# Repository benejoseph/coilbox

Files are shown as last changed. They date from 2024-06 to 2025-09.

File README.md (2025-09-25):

**The goal of this is to make a box that you can put something in and make that thing experience a magnetic field.**

**The Arduino board is there to drive a signal of your choosing. In this example it's just making a sinusoid.**

1. rp2040 propmaker from adafruit goes in the bottom
2. 24 AWG magnet wire is wrapped around the top pocket
3. put the device under test in the box
4. blue light goes on when coil is on

Other pro tips
1. The spindle is there so you can wrap your magnet wire aroudn that spindle, and then thread through the box.  Probably the spindle the magnet wire came on is too small.  Or, in "params" in the CAD program you can just change "flange top height" and "flange bottom height" to be larger and print it larger so that your magnet wire spindle can fit.
2. jig2 is the name of the FreeCAD file that has the coil box 
3. I did probably 100 wraps of 24 AWG and got about 5 ohms, and easily got over +/-400 uT of field in the box.  This was most of the 4 oz roll of 24 AWG magnet wire. 
4. I ended up drilling and tapping M2.5 threads into the holes in the back.  I recommend getting a kit of this stuff.  In the end I used 4x M2.5 * 12mm screws, M2.5 * 10mm female-female spacers, and M2.5 * 6mm screws to attach the propmaker.  And... the two holes near the terminal of the propmaker is too narrow to get the screws in. oops.
5. IDE setup -- follow the [adafruit instructions](https://learn.adafruit.com/adafruit-rp2040-prop-maker-feather/arduino-ide-setup) for the rp2040 prop maker.

### pictures of the box completed
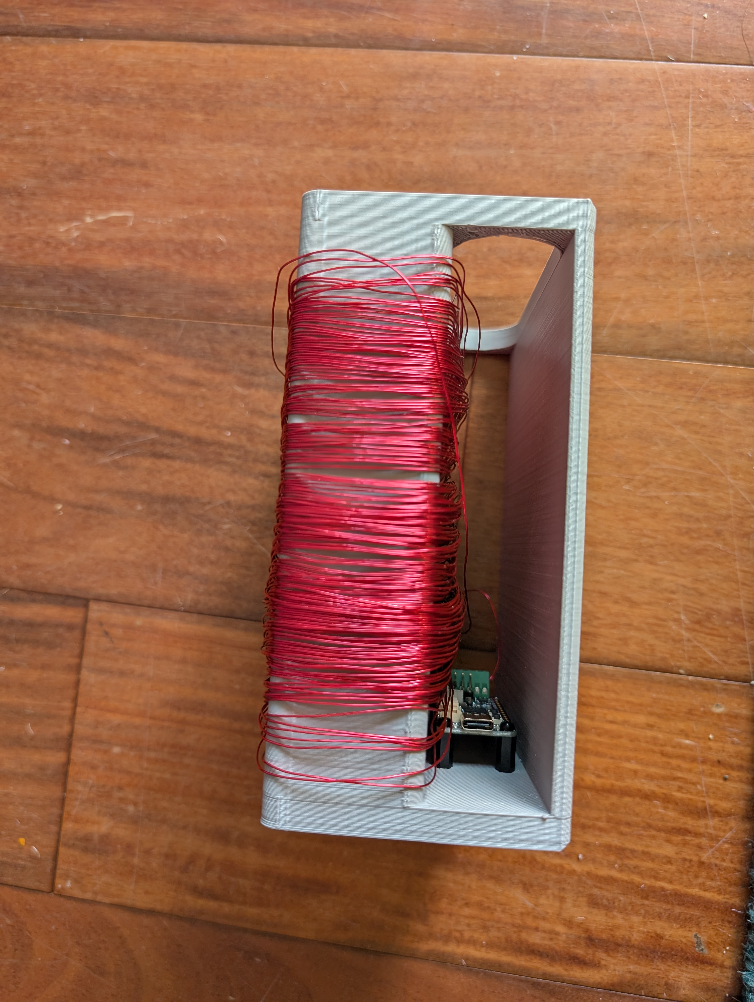
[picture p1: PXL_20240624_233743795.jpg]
looking into the box Looking into the box

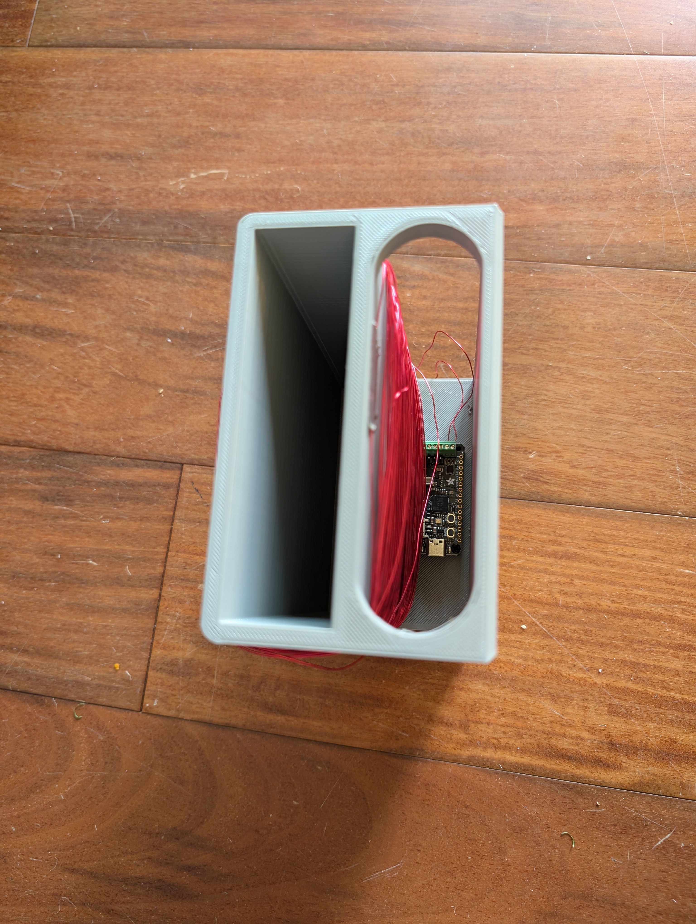
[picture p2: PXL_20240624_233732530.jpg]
side view Side View

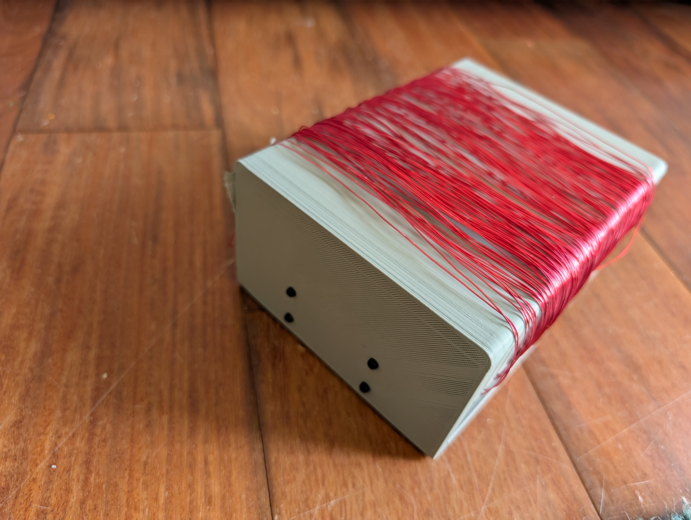
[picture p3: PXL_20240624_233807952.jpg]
rear view Rear View


### 15hz sinuosid (measured output, measured output PSD)
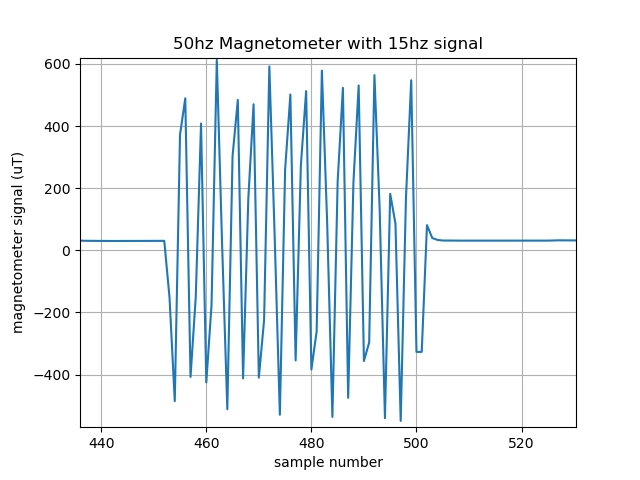
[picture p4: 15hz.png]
15hz time series from make_sinusoid

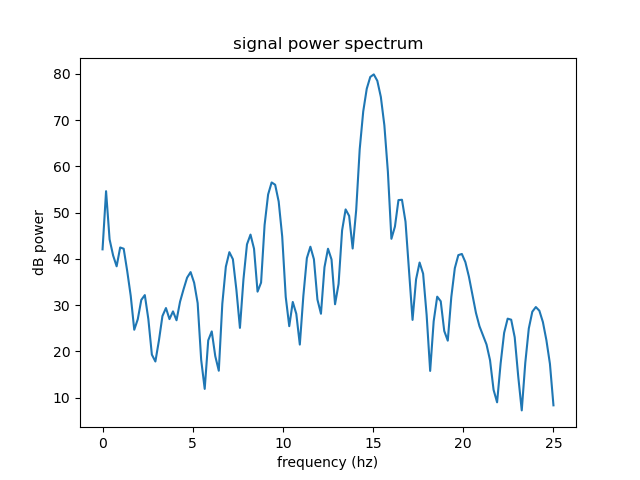
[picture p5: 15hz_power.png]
15hz PSD


### pulse (input waveform, measured output)
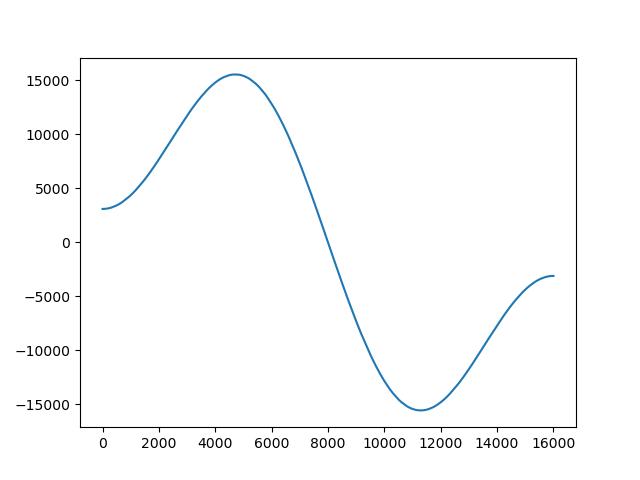
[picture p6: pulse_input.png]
pulse input waveform

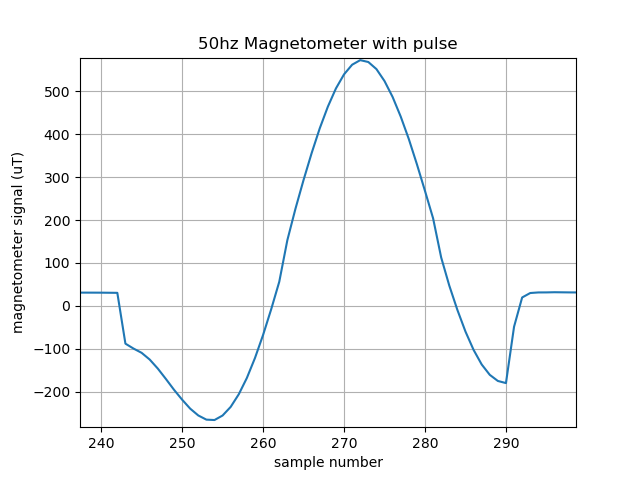
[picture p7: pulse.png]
pulse output


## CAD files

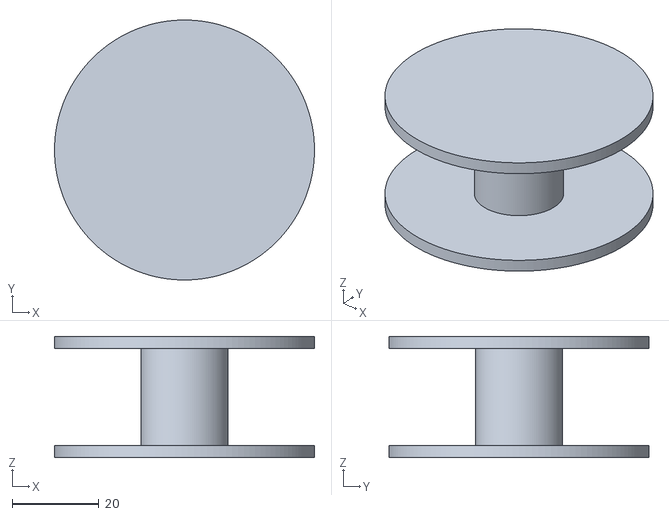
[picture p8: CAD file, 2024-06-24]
spindle-Body.stl
60.0 x 60.0 x 28.0

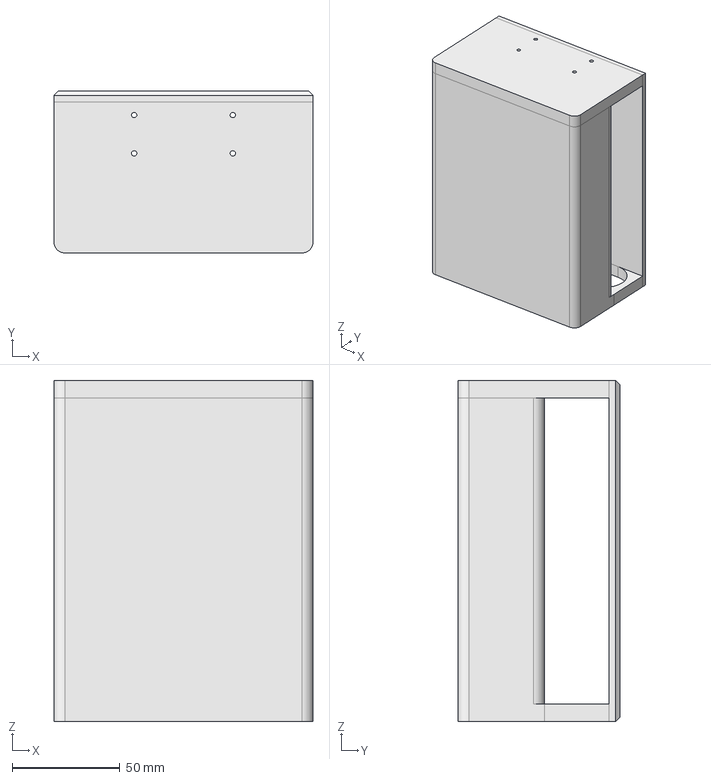
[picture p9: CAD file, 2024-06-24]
jig2.FCStd
120.0 x 75.0 x 158.0 mm

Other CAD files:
spindle.FCStd
jig2-Body.stl

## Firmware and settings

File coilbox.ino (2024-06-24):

#include <Adafruit_NeoPixel.h>
#include <Adafruit_LIS3DH.h>
#include <Adafruit_Sensor.h>
#include <I2S.h>

#include "sinusoid_samples.h"

#define ON_BOARD_RGB_PIN (D4)
#define BEACON_PERIOD_MILLIS (5000)
#define VOLUME_DOWN_BITS (2)

int led = LED_BUILTIN;
Adafruit_NeoPixel on_board_rgb_led = Adafruit_NeoPixel(1, ON_BOARD_RGB_PIN, NEO_GRB + NEO_KHZ800);
Adafruit_LIS3DH accel = Adafruit_LIS3DH();
unsigned int count = 0;

I2S i2s(OUTPUT);

bool is_playing_sound = false;

void PlayI2S(const int16_t *data, uint32_t len, uint32_t rate) {
  is_playing_sound = true;

  // start I2S at the sample rate with 16-bits per sample
  if (!i2s.begin(rate)) {
    Serial.println("Failed to initialize I2S!");
    delay(500);
    i2s.end();
    return;
  }
  
  for(uint32_t i=0; i<len; i++) {
   // uint16_t sample = (uint16_t)data[i] * 32;
    // write the same sample twice, once for left and once for the right channel
    int32_t signed_sample = static_cast<int32_t>(data[i]);
    signed_sample >>= VOLUME_DOWN_BITS;
    i2s.write(signed_sample);
    i2s.write(signed_sample);
  }
  i2s.end();
  is_playing_sound = false;
}


void setup() {
  pinMode(PIN_EXTERNAL_POWER, OUTPUT);

  // Some boards work best if we also make a serial connection
  Serial.begin(115200);

  // set LED to be an output pin
  pinMode(led, OUTPUT);
  on_board_rgb_led.begin();
  accel.begin(0x18);
  
  accel.setRange(LIS3DH_RANGE_16_G); 
  accel.setDataRate(LIS3DH_DATARATE_25_HZ);
}

void loop() {
  
  
  delay(50);                // wait for a half second
  digitalWrite(led, LOW);    // turn the LED off by making the voltage LOW
  uint32_t r = 0;
  uint32_t g = 0;
  uint32_t b = 0;

  if (is_playing_sound) {
    digitalWrite(led, HIGH);   // turn the LED on (HIGH is the voltage level)
    r = 0;
    b = 255;
  }

  on_board_rgb_led.setPixelColor(0, on_board_rgb_led.Color(r,g,b));
  on_board_rgb_led.show();


 
}

void setup1(void) {
  i2s.setBCLK(PIN_I2S_BIT_CLOCK);
  i2s.setDATA(PIN_I2S_DATA);
  i2s.setBitsPerSample(16);
}

void loop1() {
  Serial.printf("Core #2 Playing audio");
  digitalWrite(PIN_EXTERNAL_POWER, HIGH);
  PlayI2S(kSamples, kNumSamples, kSampleRateHz);
  digitalWrite(PIN_EXTERNAL_POWER, LOW);
  delay(BEACON_PERIOD_MILLIS);
}
